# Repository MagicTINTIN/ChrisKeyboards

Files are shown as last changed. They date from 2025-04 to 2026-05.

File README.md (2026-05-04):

# ChrisKeyboards
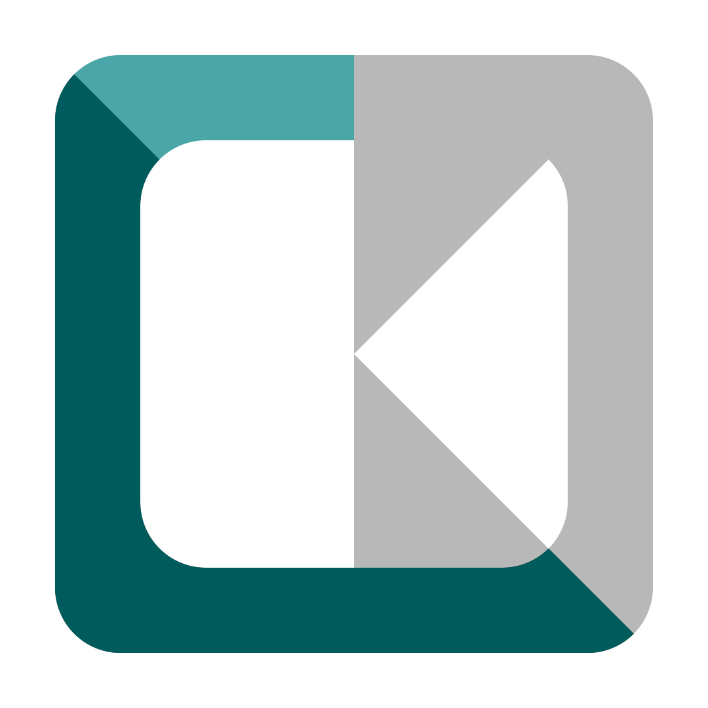
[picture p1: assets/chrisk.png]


> I couldn’t find the keyboard I wanted, so I built it.

---
Unable to find an USB chiclet keyboard as we have on laptop (and with a reasonable price), I decided to create mine.\
We can recover keyboard from an old laptop or buy a spare one (the one I chose is exactly the same that I have on my laptop, with backlight so it cost me 36 euros, but you can easily find cheaper ones).

## Components
- spare laptop keyboard (here with a 30 pins 0.8mm FPC ribbon)
- ESP32-S3 (we need about 30 IO pins...)
- 2 FPC connectors: 30 pins 0.8mm `for keys`, 6 pins (couldn't find 4 pins that meet requirements) 1mm `for backlight`
- Dupont cables while we don't have PCB
- (optional) speaker

## Road map
- [x] get components
- [x] assemble everything on a breadboard
- [x] program the esp32
- [x] testing the prototype in real conditions
- [x] implement missing features
- [ ] design PCB
- [ ] 3D model the case
- [ ] get last components
- [ ] print the case
- [ ] assemble the final keyboard

## Project pictures
ChrisT1_proto

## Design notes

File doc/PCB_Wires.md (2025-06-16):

I       30 ~        -
I7      29 ~        XX
I6      28 ~        XX
I4      27 ~        XX
I2      26 ~        XX
I5      25 ~        XX
I1      24 ~        XX
I3      23 ~        XX
IO      22 ~        XX
O5      21 ~        XX
O4      20 ~        XX
O7      19 ~        XX
O6      18 ~        XX
O8      17 ~        XX
O3      16 ~        XX
O1      15 ~        XX
O2      14 ~        XX
O0      13 ~        XX
O12     12 ~        XX
O16     11 ~        XX
O15     10 ~        XX
O13     09 ~        XX
O14     08 ~        XX
O9      07 ~        XX
O11     06 ~        XX
O10     05 ~        XX
CAP     04 ~   LED  XX (with R between them R1 = 220Ω)
o       03 ~        -
o       02 ~        -
o       01 ~   GND
Info    FPC-PIN     GPIO

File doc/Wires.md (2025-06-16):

S:  GPIO    I/PIN
-
I0: 40 ->  9|22
I1: 41 ->  7|24
I2: 42 ->  5|26
I3: 35 ->  8|23 //prev G43
I4: 36 ->  4|27 //prev G44
I5: 45 ->  6|25
I6: 47 ->  3|28
I7: 48 ->  2|29
O0: 4  -> 18|13
O1: 5  -> 16|15
O2: 6  -> 17|14
O3: 7  -> 15|16
O4: 8  -> 11|20
O5: 9  -> 10|21
O6: 10 -> 13|18
O7: 11 -> 12|19
O8: 12 -> 14|17
O9: 13 -> 24|7
O10:14 -> 26|5
O11:15 -> 25|6
O12:16 -> 19|12
O13:17 -> 22|9
O14:18 -> 23|8
O15:37 -> 21|10 //prev G19
O16:38 -> 20|11 //prev G20
LED:21 -> 27|4
-
-
GND

FPC-PIN     GPIO
02|29       48
03|28       47
04|27       44
05|26       42
06|25       45
07|24       41
08|23       43
09|22       40
10|21       9
11|20       8
12|19       11
13|18       10
14|17       12
15|16       7
16|15       5
17|14       6
18|13       4
19|12       16
20|11       20
21|10       19
22|9        17
23|8        18
24|7        13
25|6        15
26|5        14

FPC-PIN     GPIO
30 ~        -
29 ~        48
28 ~        47
27 ~        44
26 ~        42
25 ~        45
24 ~        41
23 ~        43
22 ~        40
21 ~        9
20 ~        8
19 ~        11
18 ~        10
17 ~        12
16 ~        7
15 ~        5
14 ~        6
13 ~        4
12 ~        16
11 ~        20
10 ~        19
09 ~        17
08 ~        18
07 ~        13
06 ~        15
05 ~        14
04 ~   LED  21 with R between them R1 = 220Ω
03 ~        -
02 ~        -
01 ~   GND

-
I0: -> 22
I1: -> 24
I2: -> 26
I3: -> 23
I4: -> 27
I5: -> 25
I6: -> 28
I7: -> 29
O0: -> 13
O1: -> 15
O2: -> 14
O3: -> 16
O4: -> 20
O5: -> 21
O6: -> 18
O7: -> 19
O8: -> 17
O9: -> 7
O10 -> 5
O11 -> 6
O12 -> 12
O13 -> 9
O14 -> 8
O15 -> 10
O16 -> 11
LED -> 4
-
-
GND

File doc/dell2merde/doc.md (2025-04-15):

Globalement y a pas grand chose à trouver sur internet.

Alors que : OMG
https://www.gadget-manual.com/dell/dell-laptop-schematics/

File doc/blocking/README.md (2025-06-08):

# Comment fonctionne l'algo de blocage pour empêcher les ghost keys
voici notre matrice de touches avec les colonnes 1 à 3 et nos lignes A à D permettant d'appuyer sur les touches 1 à C.
> [!NOTE]
> La matrice `mat` contient des booléens (réinitialisés à 0=false avant chaque frame)

> [!NOTE] Note n°2
> Ici la représentation suggère les colonnes envoient du courant séquentiellement. La représentation est plus compréhensible comme ça et cela fonctionne, mais ce n'est pas exactement ce qui est utilisé dans notre cas. Nous utilisons des colonnes en pull up qui passent en output open drain envoyant un 0 lorsqu'elles sont "actives" dans le scan, et repassent immédiatement après en input pull up.

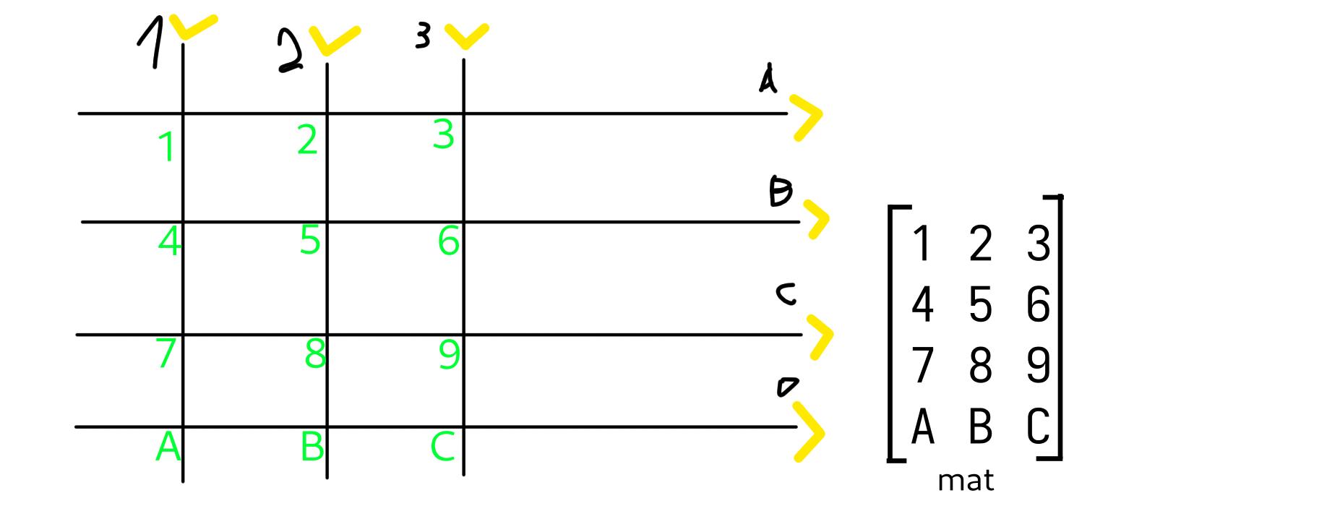
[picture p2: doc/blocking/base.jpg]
représentation de la matrice du clavier


## Scan sans problème
On décide d'appuyer sur 1 et C en premier
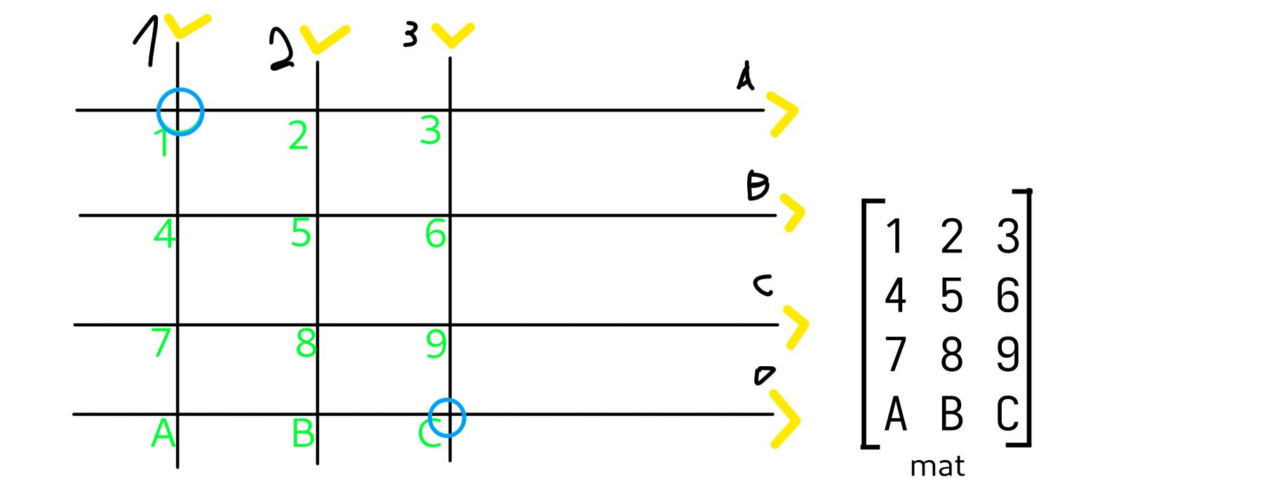
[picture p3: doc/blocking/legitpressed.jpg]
appui sur les touches 1 et C


Le scan passe et tout va bien
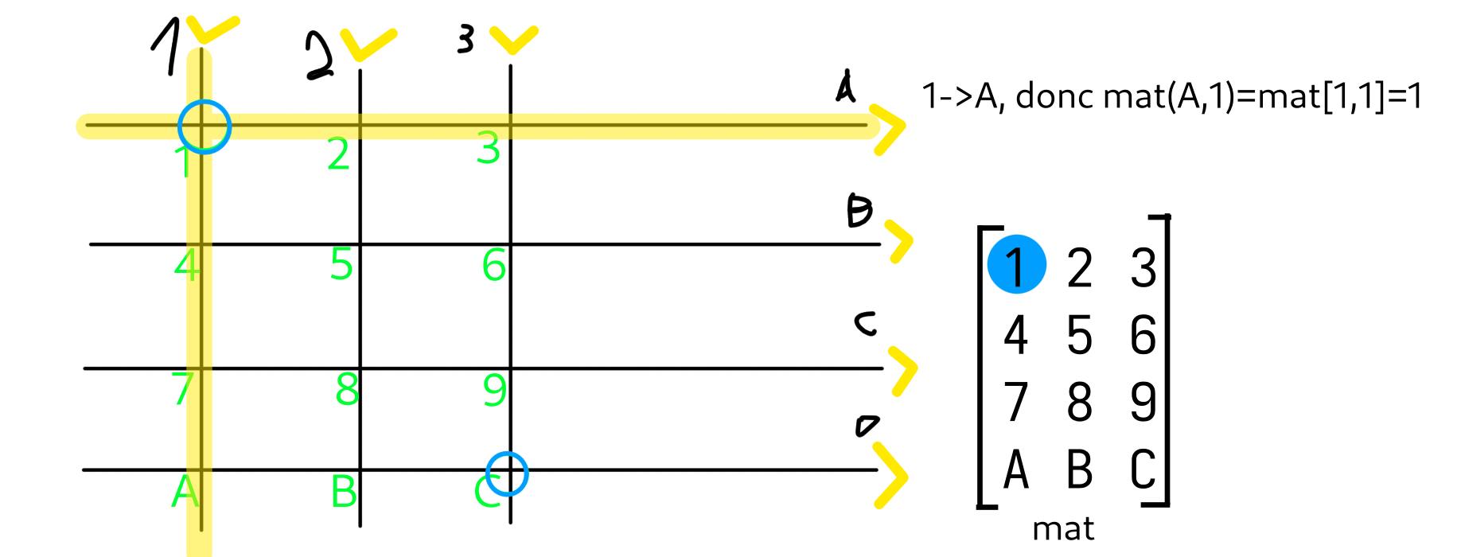
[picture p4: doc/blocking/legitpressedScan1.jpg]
Scan n°1 des touches 1 et C

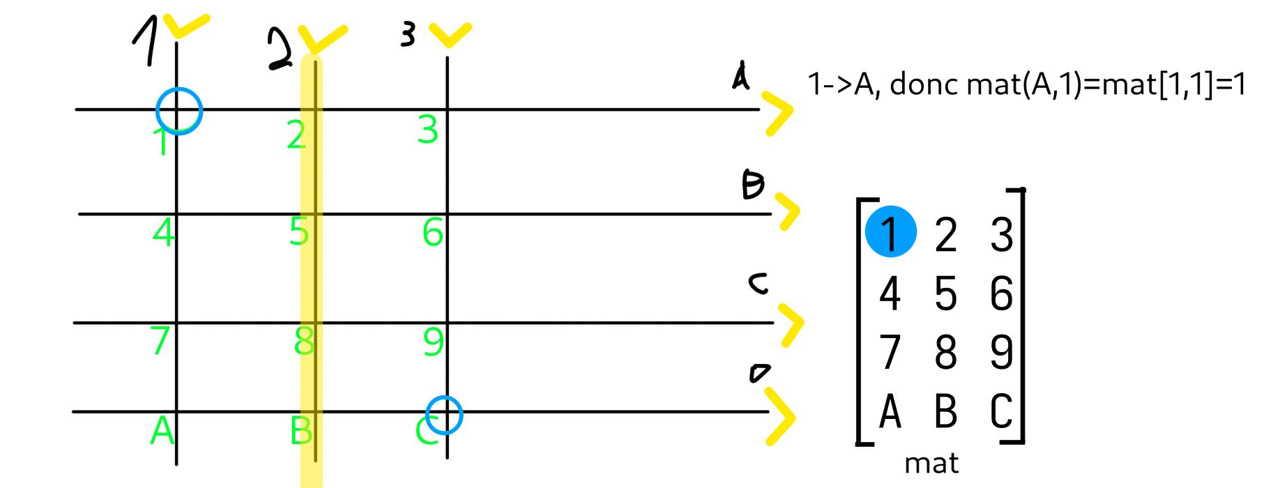
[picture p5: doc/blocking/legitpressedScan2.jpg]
Scan n°2 des touches 1 et C

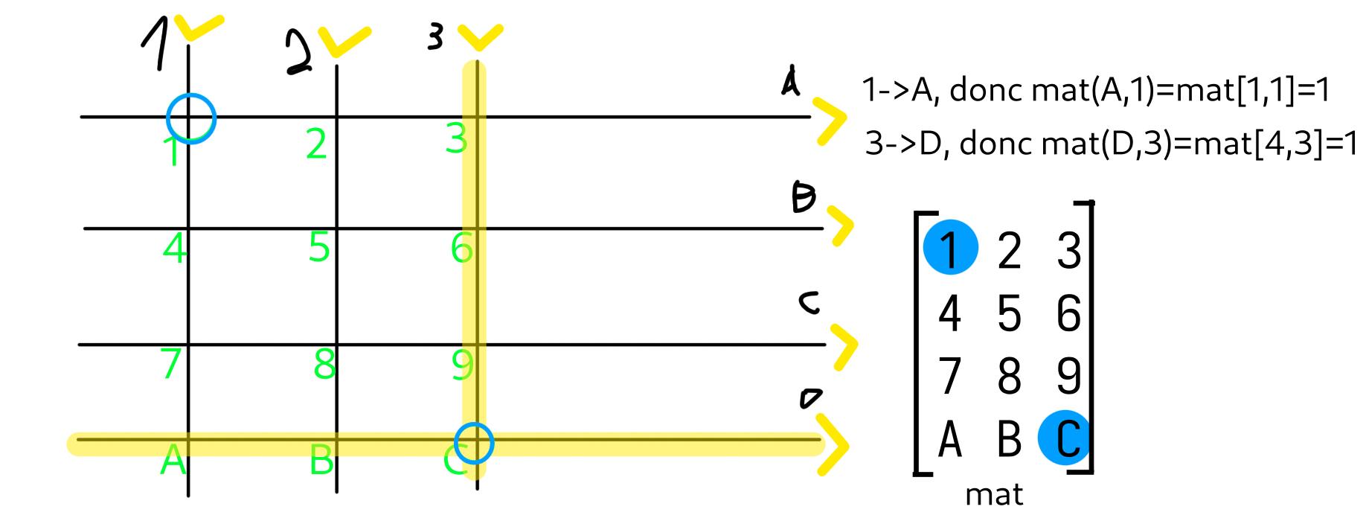
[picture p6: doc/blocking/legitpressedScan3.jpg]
Scan n°3 des touches 1 et C


Les touches détectées sont bonnes
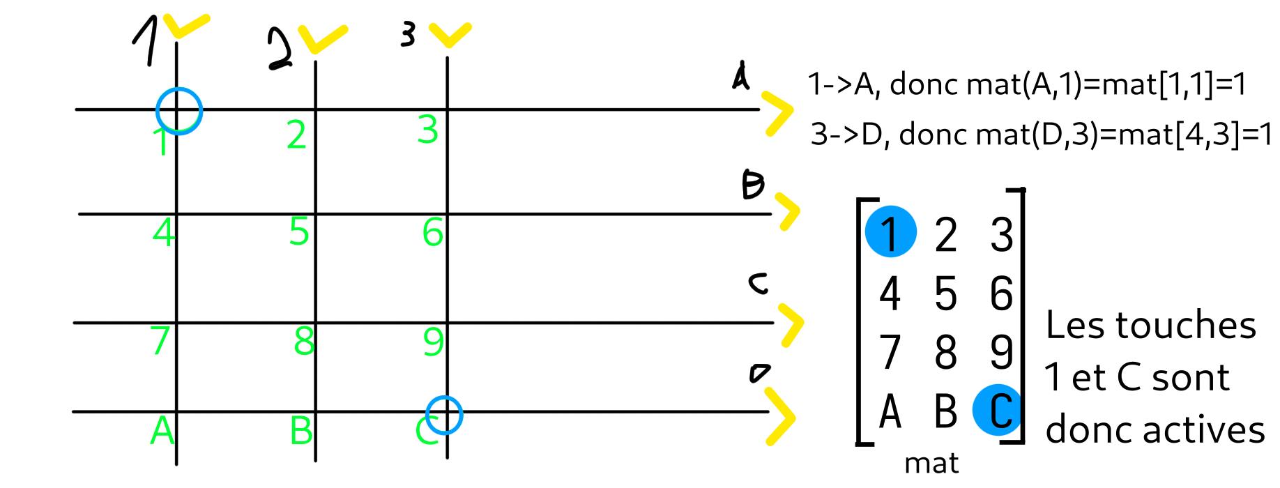
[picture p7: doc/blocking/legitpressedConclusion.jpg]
Conclusion du scanner sur 1 et C


## Le problème : apparition de ghost key

On décide maintenant d'ajouter A.
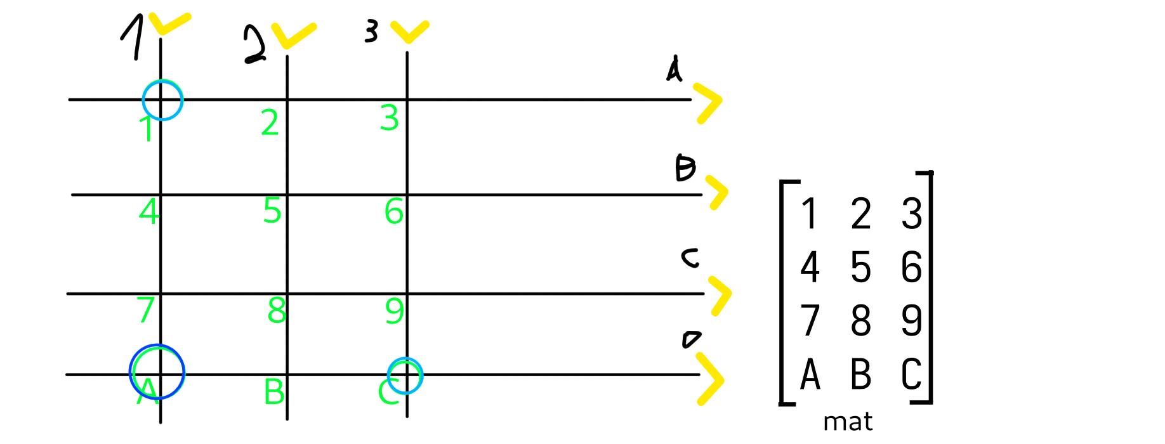
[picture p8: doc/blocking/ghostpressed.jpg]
appui sur les touches 1, A et C


Le scan passe et révèle 4 touches pressées
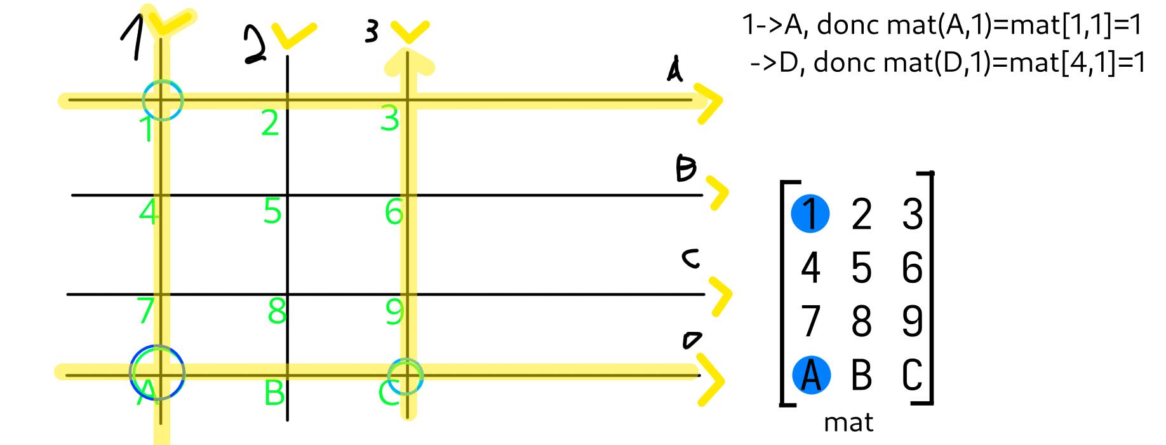
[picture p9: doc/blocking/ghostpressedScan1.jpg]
Scan n°1 des touches 1, A et C

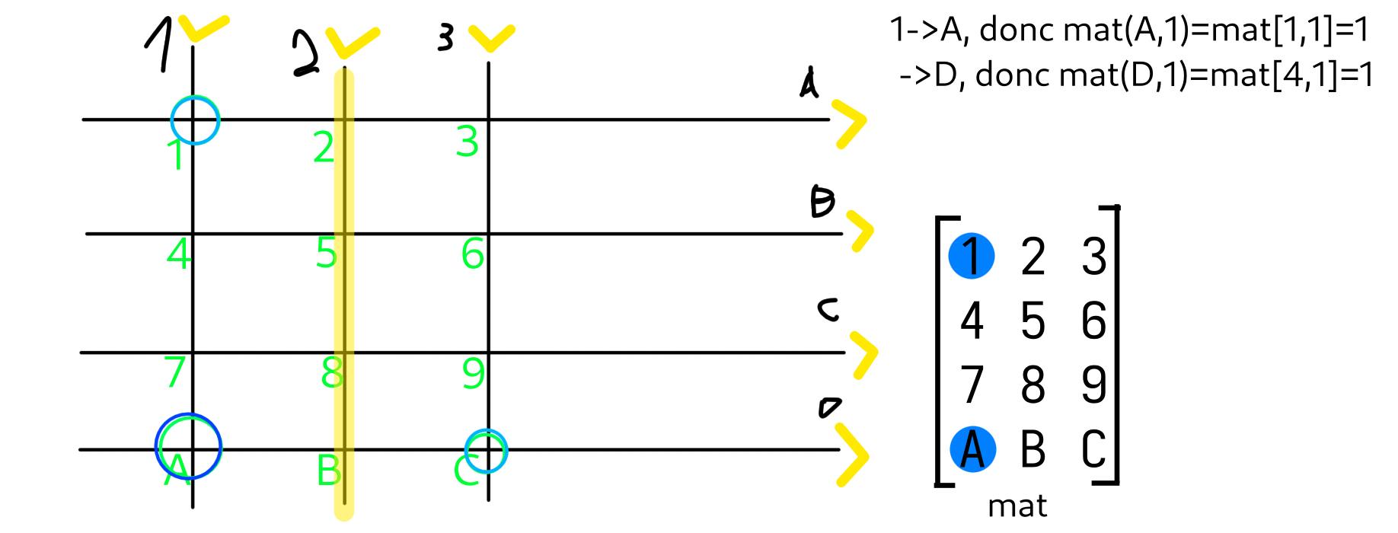
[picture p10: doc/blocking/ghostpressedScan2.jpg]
Scan n°2 des touches 1, A et C

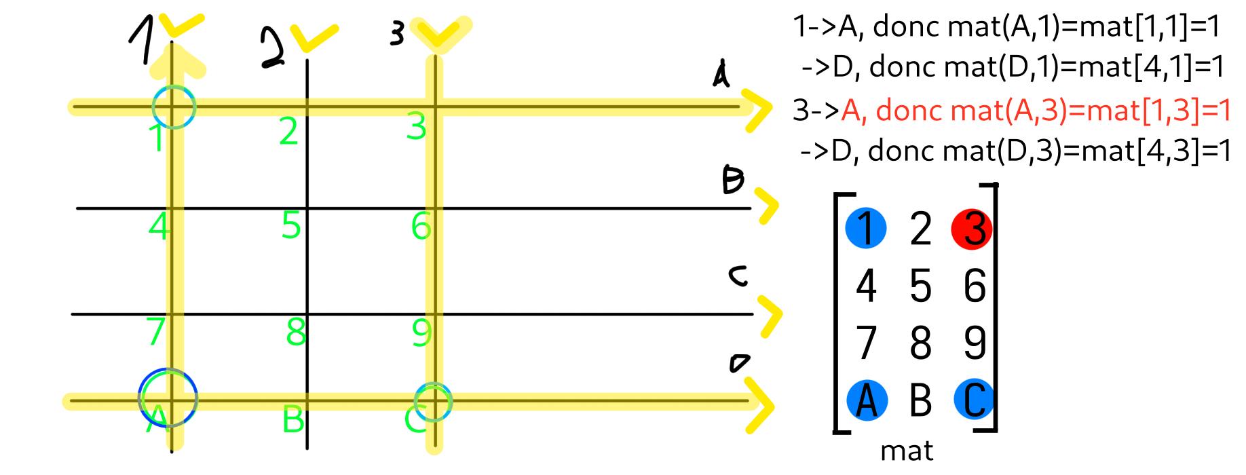
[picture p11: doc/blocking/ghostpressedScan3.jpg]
Scan n°3 des touches 1, A et C


La touche 3 est une ghost key
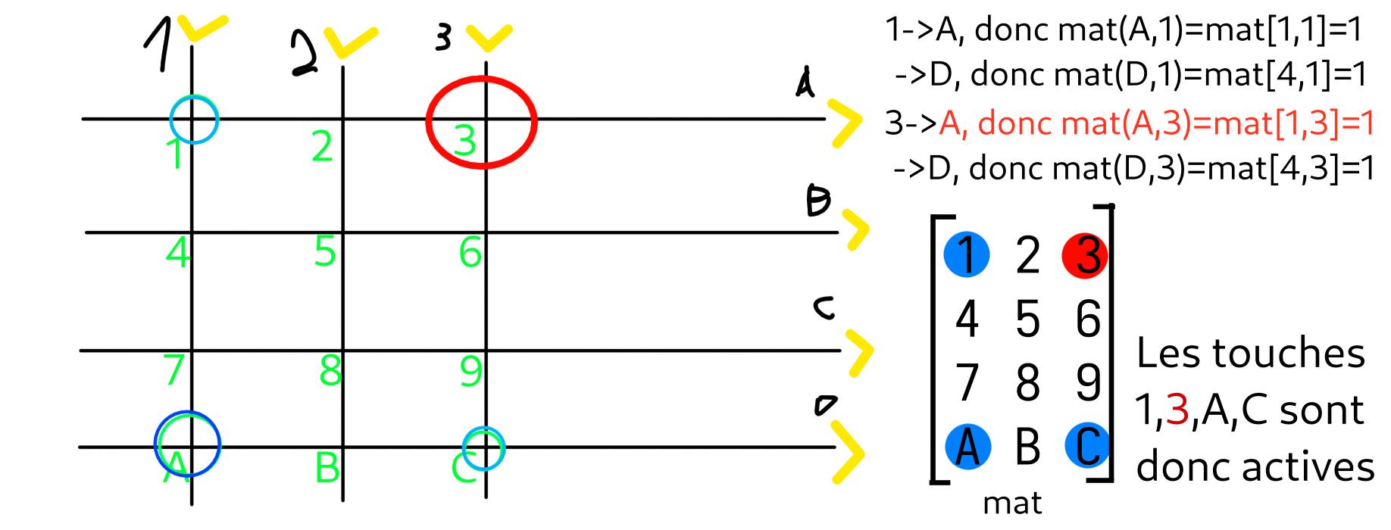
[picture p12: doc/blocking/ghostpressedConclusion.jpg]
Conclusion du scanner sur 1, A et C


## La solution
La solution pour les claviers diodeless est donc d'ajouter un algorithme de blocage. Celui-ci se trouve entre le scan et l'envoi des touches au système d'exploitation.
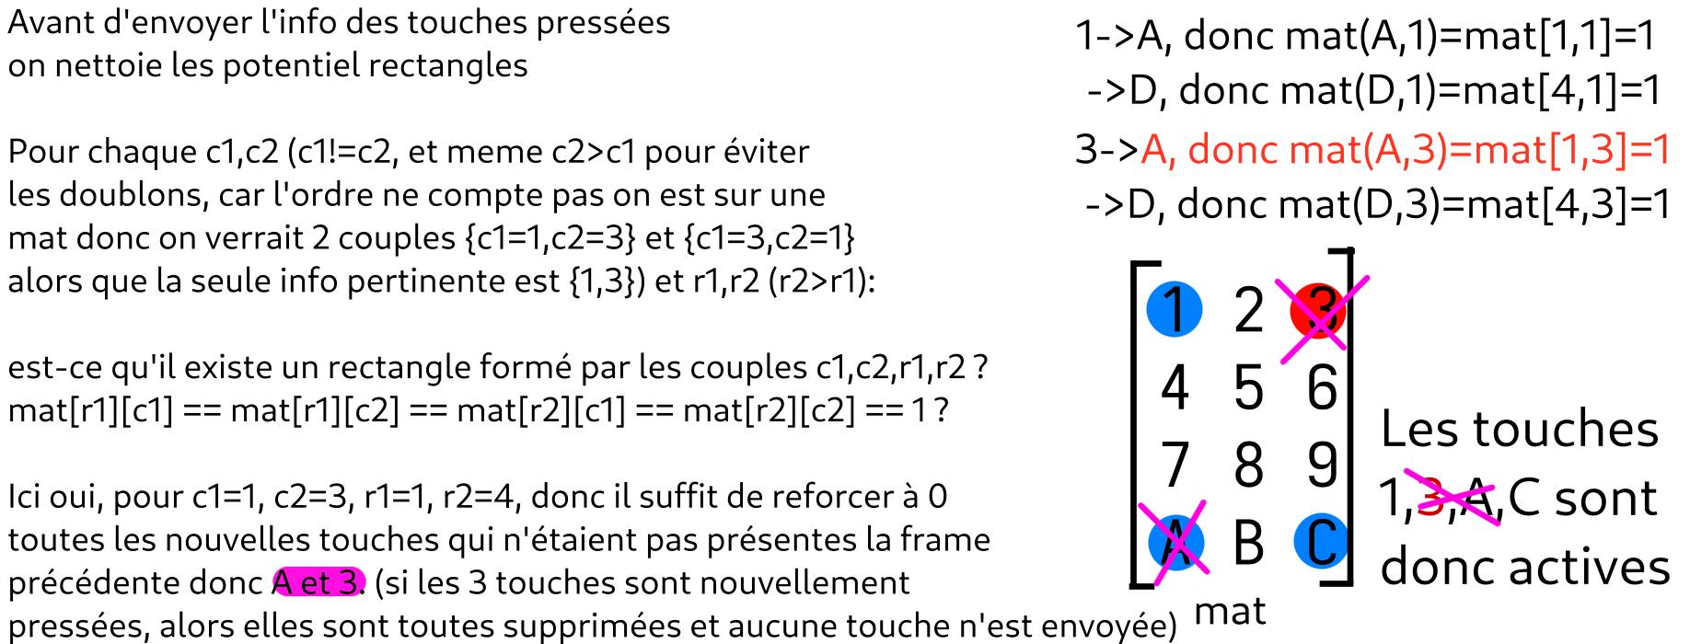
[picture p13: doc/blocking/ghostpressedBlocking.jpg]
Algoirthme solution


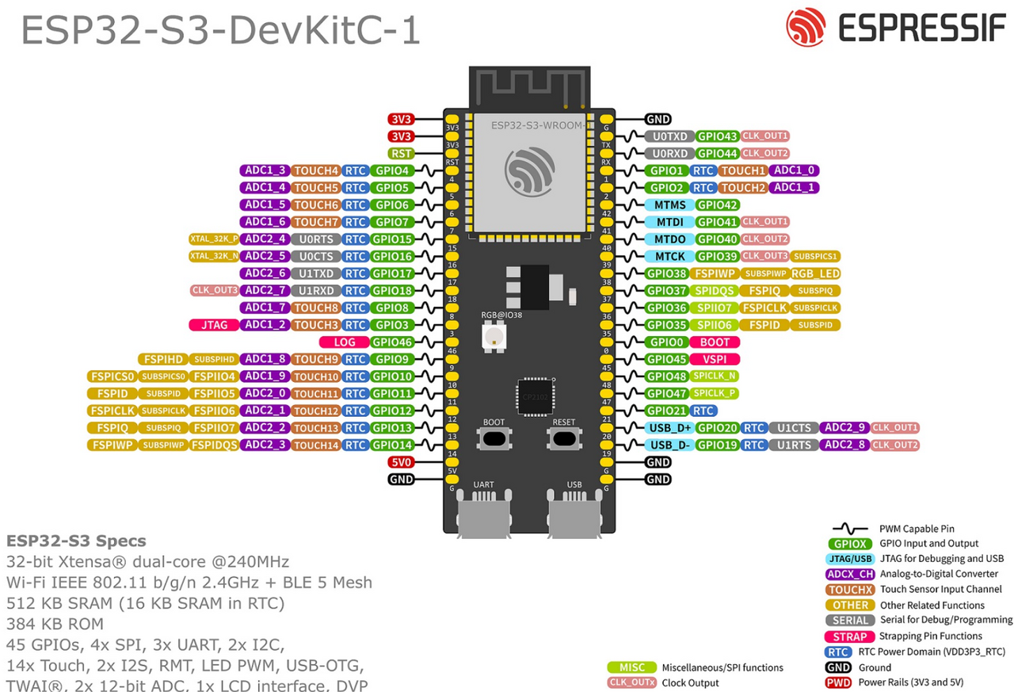
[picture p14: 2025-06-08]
doc/esp32/esp202b-3300364196.png

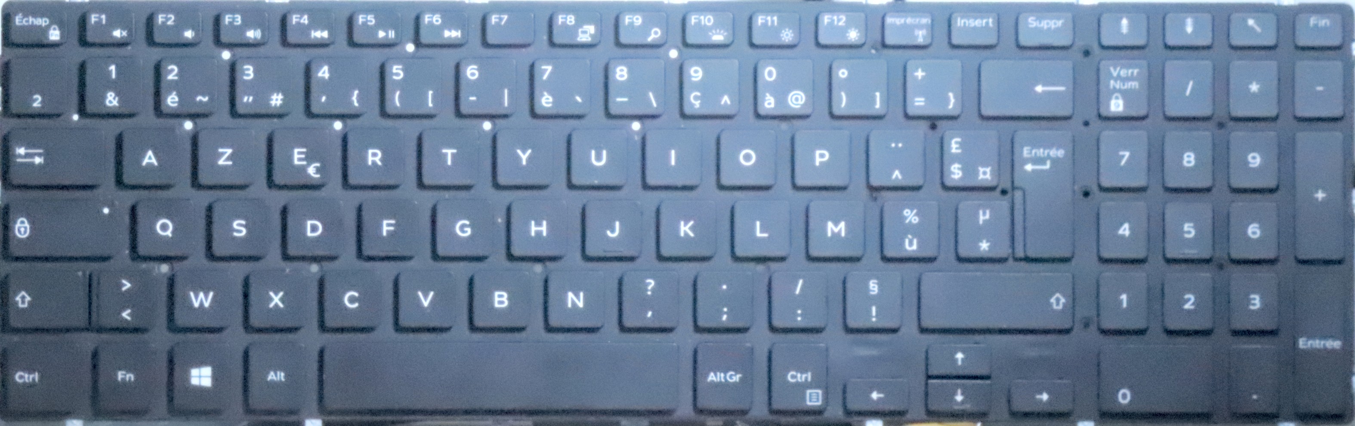
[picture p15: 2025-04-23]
doc/dell2merde/photo1280mm.jpg

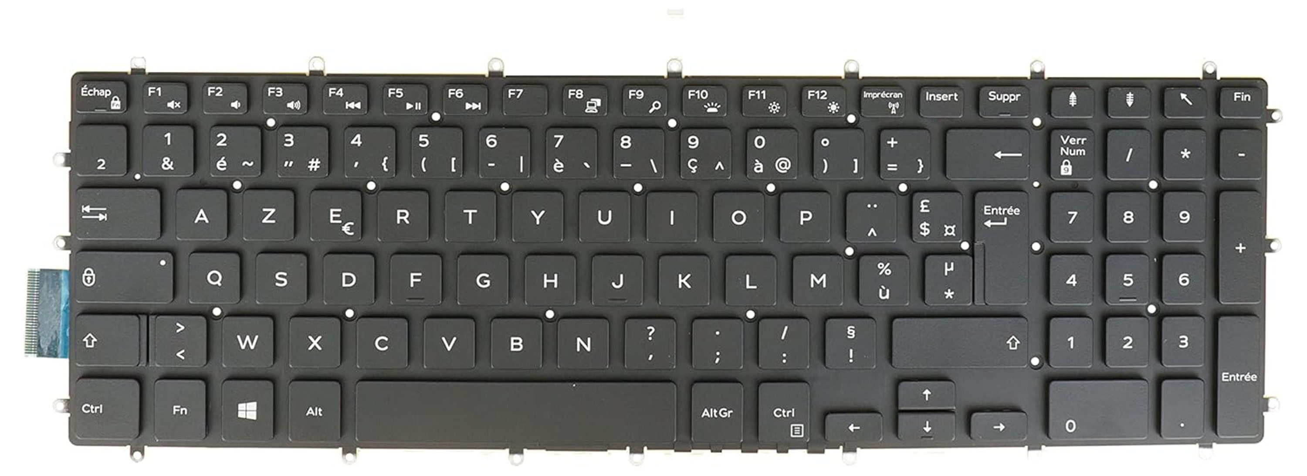
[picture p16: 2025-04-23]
doc/dell2merde/kbd.jpg

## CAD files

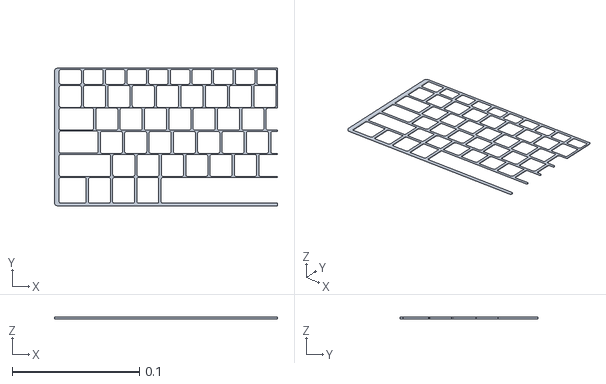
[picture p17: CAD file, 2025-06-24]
3DModel/split1m.stl
0.175 x 0.108 x 0.0012

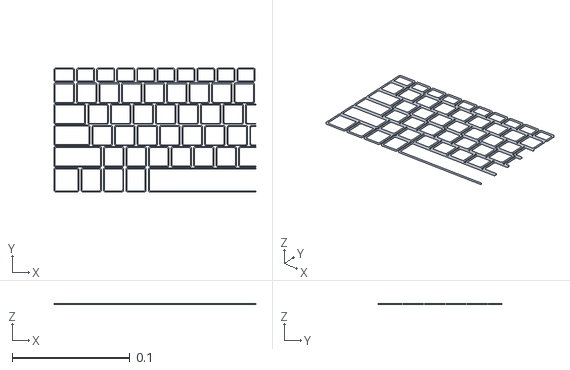
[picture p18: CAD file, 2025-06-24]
3DModel/split1c.stl
0.171 x 0.105 x 0.0012

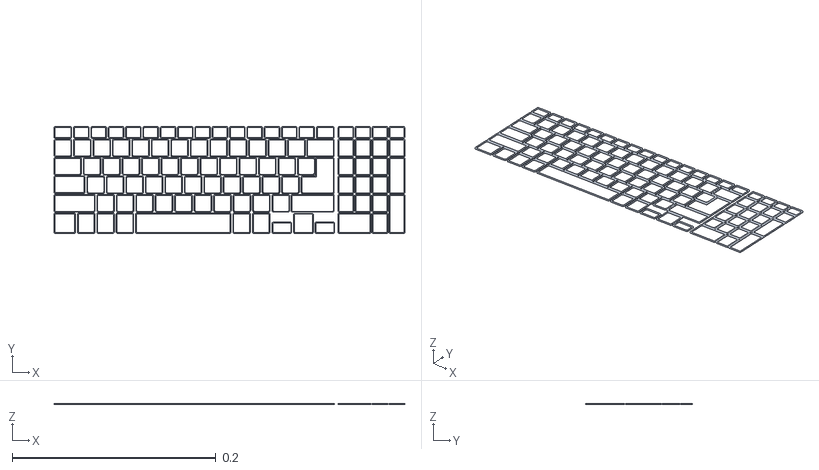
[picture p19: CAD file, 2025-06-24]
3DModel/v0.2c.stl
0.344 x 0.105 x 0.0012

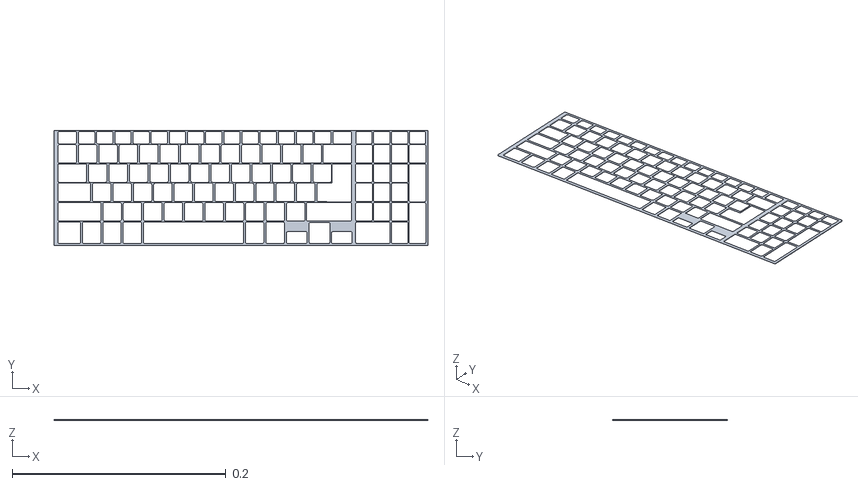
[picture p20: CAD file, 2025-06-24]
3DModel/v0.2m.stl
0.35 x 0.108 x 0.0012

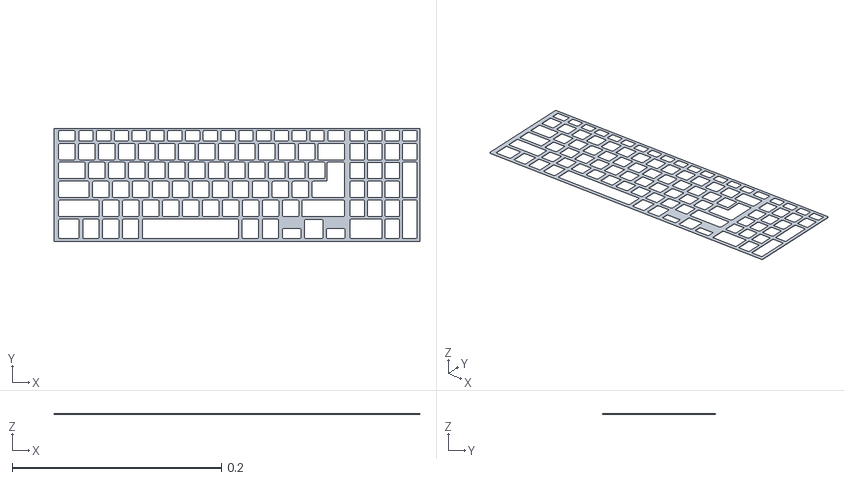
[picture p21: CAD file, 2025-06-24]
3DModel/v0.2.stl
0.35 x 0.108 x 0.0012

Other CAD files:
3DModel/v0.2.blend
3DModel/v0.blend

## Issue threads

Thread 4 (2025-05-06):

BUG: fnLock weird behaviour

MagicTINTIN, 2025-05-06:
Maybe no delay while switching from Locked or not ?

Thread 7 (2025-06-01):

feat: extension card

MagicTINTIN, 2025-06-01:
Check availability for extension.
1. in
2. out
3. clock
4. GND
5. 3.3V

Protocol to be defined between them.

Extension with a pico ? or nano.
- requirements for screen
- requirements for SD card R/W
- requirements for audio ? (jack)
- usb hub ?
- 5V ?

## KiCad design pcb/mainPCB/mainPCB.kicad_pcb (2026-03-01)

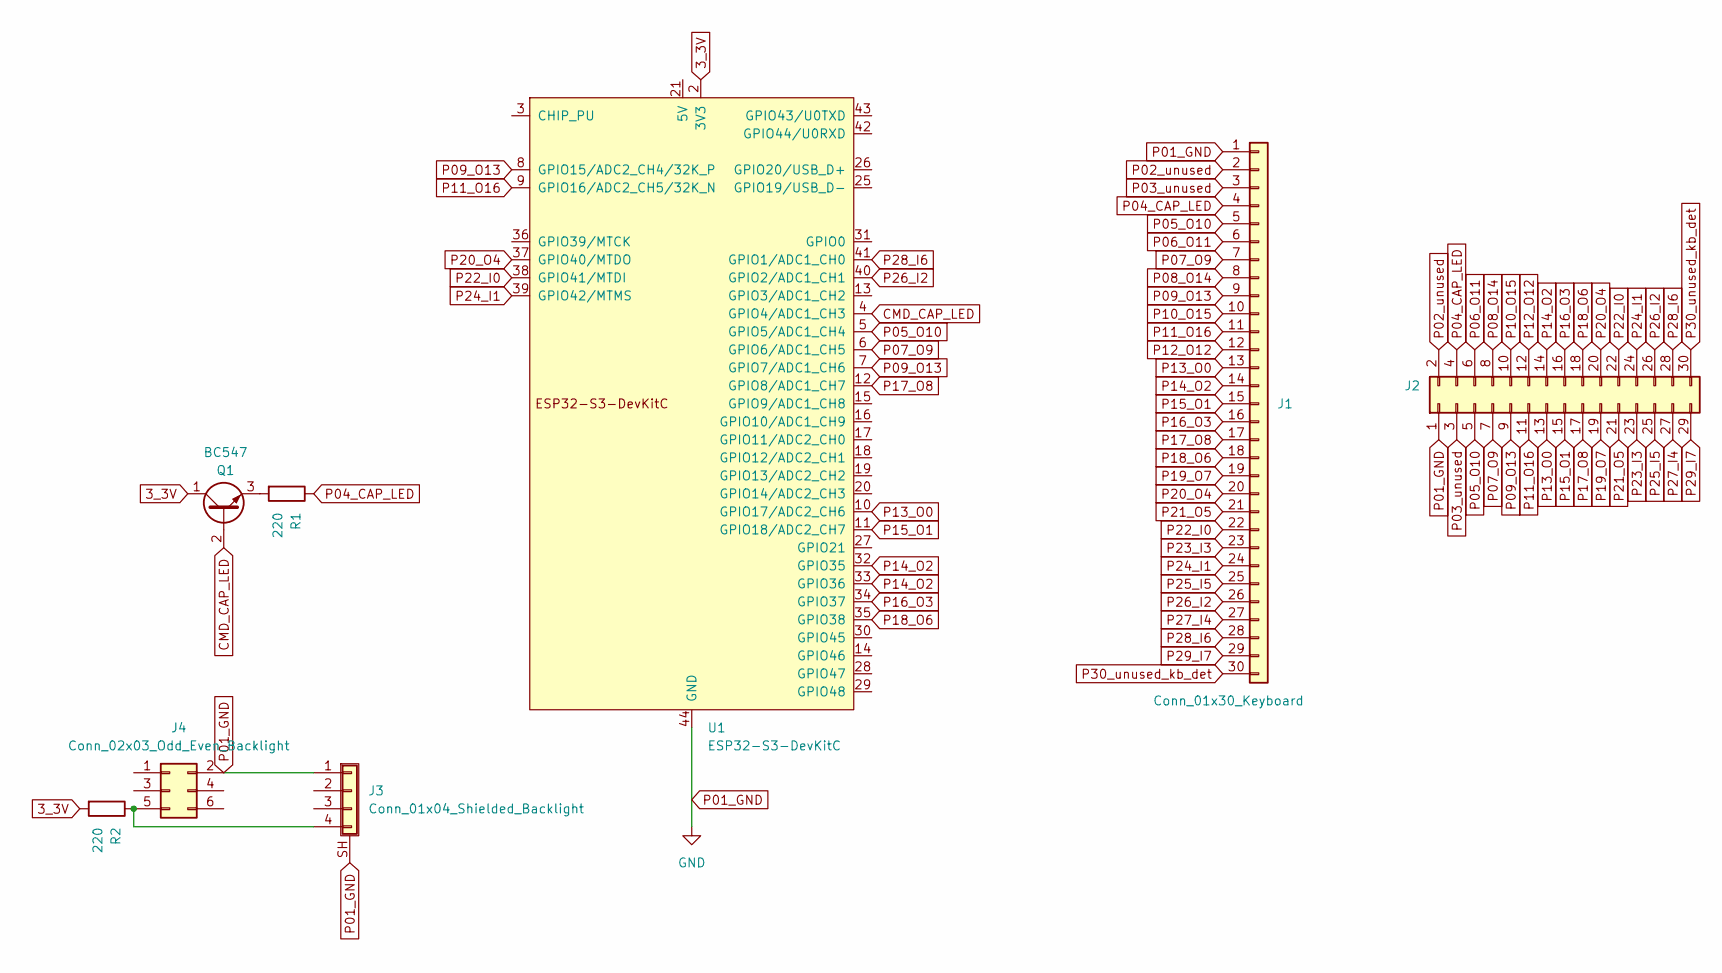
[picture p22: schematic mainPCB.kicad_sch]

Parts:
J1: Conn_01x30_Keyboard; FPC_30_Dell_0.8mm_no0
J2: Conn_02x15_Counter_Clockwise; PinHeader_2x15_P2.54mm_Vertical
J3: Conn_01x04_Shielded_Backlight; FPC_4_Dell_1mm_with0
J4: Conn_02x03_Odd_Even_Backlight; PinHeader_2x03_P2.00mm_Vertical
Q1: BC547; TO-92_Inline
R1, R2: 220; R_Axial_DIN0207_L6.3mm_D2.5mm_P10.16mm_Horizontal
U1: ESP32-S3-DevKitC

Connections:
3_3V: Q1.1 (C), R2.2, U1.1 (3V3), U1.2 (3V3)
CMD_CAP_LED: Q1.2 (B), U1.4 (GPIO4/ADC1_CH3)
unnamed: J3.4, J4.5, R2.1
unnamed: Q1.3 (E), R1.2
P01_GND: J1.1, J2.1, J3.1, J3.SH (Shield), J4.2, U1.22 (GND), U1.23 (GND), U1.24 (GND), U1.44 (GND)
P02_unused: J1.2, J2.2
P03_unused: J1.3, J2.3
P04_CAP_LED: J1.4, J2.4, R1.1
P05_O10: J1.5, J2.5, U1.5 (GPIO5/ADC1_CH4)
P06_O11: J1.6, J2.6
P07_O9: J1.7, J2.7, U1.6 (GPIO6/ADC1_CH5)
P08_O14: J1.8, J2.8
P09_O13: J1.9, J2.9, U1.7 (GPIO7/ADC1_CH6), U1.8 (GPIO15/ADC2_CH4/32K_P)
P10_O15: J1.10, J2.10
P11_O16: J1.11, J2.11, U1.9 (GPIO16/ADC2_CH5/32K_N)
P12_O12: J1.12, J2.12
P13_O0: J1.13, J2.13, U1.10 (GPIO17/ADC2_CH6)
P14_O2: J1.14, J2.14, U1.32 (GPIO35), U1.33 (GPIO36)
P15_O1: J1.15, J2.15, U1.11 (GPIO18/ADC2_CH7)
P16_O3: J1.16, J2.16, U1.34 (GPIO37)
P17_O8: J1.17, J2.17, U1.12 (GPIO8/ADC1_CH7)
P18_O6: J1.18, J2.18, U1.35 (GPIO38)
P19_O7: J1.19, J2.19
P20_O4: J1.20, J2.20, U1.37 (GPIO40/MTDO)
P21_O5: J1.21, J2.21
P22_I0: J1.22, J2.22, U1.38 (GPIO41/MTDI)
P23_I3: J1.23, J2.23
P24_I1: J1.24, J2.24, U1.39 (GPIO42/MTMS)
P25_I5: J1.25, J2.25
P26_I2: J1.26, J2.26, U1.40 (GPIO2/ADC1_CH1)
P27_I4: J1.27, J2.27
P28_I6: J1.28, J2.28, U1.41 (GPIO1/ADC1_CH0)
P29_I7: J1.29, J2.29
P30_unused_kb_det: J1.30, J2.30

Board: 2 copper layers, 8 parts (0 on the bottom side), 34 nets, no tracks yet.

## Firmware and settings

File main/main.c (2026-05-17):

// #define CFG_TUD_HID 2
#include "class/hid/hid.h"
#include "class/hid/hid_device.h"
#include "configuration.h"
#include "driver/gpio.h"
#include "driver/ledc.h"
#include "esp_log.h"
#include "freertos/FreeRTOS.h"
#include "freertos/semphr.h"
#include "freertos/task.h"
#include "nvs_flash.h"
#include "tinyusb.h"
#include <stdint.h>
#include <stdio.h>
#include <stdlib.h>
// #include "esp_task_wdt.h"
// #include <idf_additions.h>

#include "constants.h"
#include "esp_bt_defs.h"
#include "esp_gap_ble_api.h"
#include "esp_hidd_prf_api.h"
// #include "esp_bt_device.h"
// #include "esp_bt.h"
// #include "esp_bt_main.h"
// #include "esp_event.h"
// #include "esp_gatts_api.h"
// #include "esp_gatt_defs.h"
// #include "esp_system.h"
// #include "hid_dev.h"
// #include "nvs_flash.h"
#include "freertos/event_groups.h"
#include "stdio.h"
#include "string.h"

#define print_bits(x)                                                          \
  do {                                                                         \
    unsigned long long a__ = (x);                                              \
    size_t bits__ = sizeof(x) * 8;                                             \
    printf(#x ": ");                                                           \
    while (bits__--)                                                           \
      putchar(a__ & (1ULL << bits__) ? '1' : '0');                             \
    putchar('\n');                                                             \
  } while (0)

/************* TinyUSB descriptors ****************/

#define TUSB_DESC_TOTAL_LEN                                                    \
  (TUD_CONFIG_DESC_LEN + CFG_TUD_HID * TUD_HID_DESC_LEN)

// mouse and keyboard
static uint8_t const hid_mouse_keyboard_report_descriptor[] = {
    TUD_HID_REPORT_DESC_KEYBOARD(),
    // TUD_HID_REPORT_DESC_MOUSE(), // TODO:
};

// keyboard consumer (next/previous keys)
static uint8_t const hid_consumer_report_descriptor[] = {
    TUD_HID_REPORT_DESC_CONSUMER(HID_REPORT_ID(2))};

#define CONSUMER_REPORT_ID 2

// gamepad

/*
 * TUD_HID_REPORT_DESC_GAMEPAD
 * uint16_t buttons - 16 digital buttons (A/B/X/Y/LB/RB...)
 * int8_t   x, y    - left  stick  axis (-127 .. 127)
 * int8_t   z, rz   - right stick  axis (-127 .. 127)
 * int8_t   rx, ry  - analog triggers   (use  0  .. 127)
 * uint8_t  hat     - D-pad / hat switch (GAMEPAD_HAT_*)
 */
static uint8_t const hid_gamepad_report_descriptor[] = {
    TUD_HID_REPORT_DESC_GAMEPAD()};

// dummy
static const uint8_t hid_dummy1_descriptor[] = {
    HID_USAGE_PAGE_N(HID_USAGE_PAGE_VENDOR, 2),
    HID_USAGE(0x01),
    HID_COLLECTION(HID_COLLECTION_APPLICATION),
    HID_USAGE(0x01),
    HID_LOGICAL_MIN(0),
    HID_LOGICAL_MAX_N(255, 2),
    HID_REPORT_SIZE(8),
    HID_REPORT_COUNT(1),
    HID_INPUT(HID_DATA | HID_VARIABLE | HID_ABSOLUTE),
    HID_COLLECTION_END};

/**
 * @brief String descriptor
 */
const char *hid_string_descriptor[5] = {
    (char[]){4, TUSB_DESC_STRING, 0x0c, 0x04},
    "MagicTINTIN",     // 1: Manufacturer
    "ChrisT1 Clavier", // 2: Product
    "123456",          // 3: Serials, should use chip ID
    "CT1 Keyboard",    // 4: HID
};

/**
 * @brief Configuration descriptor
 *
 * This is a simple configuration descriptor that defines 1 configuration and 1
 * HID interface
 */
static const uint8_t hid_configuration_descriptor[] = {
    // Configuration number, interface count, string index, total length,
    // attribute, power in mA
    TUD_CONFIG_DESCRIPTOR(1, 5, 0, TUSB_DESC_TOTAL_LEN,
                          TUSB_DESC_CONFIG_ATT_REMOTE_WAKEUP, 100),

    // Interface number, string index, boot protocol, report descriptor len, EP
    // In address, size & polling interval
    // FIXME: booot protocol ?
    TUD_HID_DESCRIPTOR(HID_ITF_MOUSEKYB, 4, true,
                       sizeof(hid_mouse_keyboard_report_descriptor), 0x81, 16,
                       10),
    TUD_HID_DESCRIPTOR(HID_ITF_CONSUMER, 4, false,
                       sizeof(hid_consumer_report_descriptor), 0x82, 16, 10),
    TUD_HID_DESCRIPTOR(HID_ITF_GAMEPAD1, 4, false,
                       sizeof(hid_gamepad_report_descriptor), 0x83, 16, 10),
    TUD_HID_DESCRIPTOR(HID_ITF_GAMEPAD2, 4, false,
                       sizeof(hid_gamepad_report_descriptor), 0x84, 16, 10),
};

static volatile uint8_t g_enabled_gamepads_itfs = 0;
static volatile uint8_t g_enabled_gamepads_keys = 0;
static volatile uint8_t g_enabled_sounds_level = 1;

/********* TinyUSB HID callbacks ***************/

// Invoked when received GET HID REPORT DESCRIPTOR request
// Application return pointer to descriptor, whose contents must exist long
// enough for transfer to complete
uint8_t const *tud_hid_descriptor_report_cb(uint8_t instance) {
  switch (instance) {
  case HID_ITF_MOUSEKYB:
    return hid_mouse_keyboard_report_descriptor;
  case HID_ITF_CONSUMER:
    return hid_consumer_report_descriptor;
  case HID_ITF_GAMEPAD1:
    return g_enabled_gamepads_itfs > 0 ? hid_gamepad_report_descriptor
                                       : hid_dummy1_descriptor;
  case HID_ITF_GAMEPAD2:
    return g_enabled_gamepads_itfs > 1 ? hid_gamepad_report_descriptor
                                       : hid_dummy1_descriptor;
  default:
    return hid_mouse_keyboard_report_descriptor;
  }
}

// Invoked when received GET_REPORT control request
// Application must fill buffer report's content and return its length.
// Return zero will cause the stack to STALL request
uint16_t tud_hid_get_report_cb(uint8_t instance, uint8_t report_id,
                               hid_report_type_t report_type, uint8_t *buffer,
                               uint16_t reqlen) {
  (void)instance;
  (void)report_id;
  (void)report_type;
  (void)buffer;
  (void)reqlen;
  return 0;
}

static uint16_t hid_conn_id = 0;
static bool sec_conn = false;

static uint8_t hidd_service_uuid128[] = {
    /* LSB
       <-------------------------------------------------------------------------------->
       MSB */
    // first uuid, 16bit, [12],[13] is the value
    0xfb, 0x34, 0x9b, 0x5f, 0x80, 0x00, 0x00, 0x80,
    0x00, 0x10, 0x00, 0x00, 0x12, 0x18, 0x00, 0x00,
};

static esp_ble_adv_data_t hidd_adv_data = {
    .set_scan_rsp = false,
    .include_name = true,
    .include_txpower = true,
    .min_interval = 0x0006, // slave connection min interval, Time =
                            // min_interval * 1.25 msec
    .max_interval = 0x0010, // slave connection max interval, Time =
                            // max_interval * 1.25 msec
    .appearance = 0x03c0,   // HID Generic,
    .manufacturer_len = 0,
    .p_manufacturer_data = NULL,
    .service_data_len = 0,
    .p_service_data = NULL,
    .service_uuid_len = sizeof(hidd_service_uuid128),
    .p_service_uuid = hidd_service_uuid128,
    .flag = 0x6,
};

static esp_ble_adv_params_t hidd_adv_params = {
    .adv_int_min = 0x20,
    .adv_int_max = 0x30,
    .adv_type = ADV_TYPE_IND,
    .own_addr_type = BLE_ADDR_TYPE_PUBLIC,
    .channel_map = ADV_CHNL_ALL,
    .adv_filter_policy = ADV_FILTER_ALLOW_SCAN_ANY_CON_ANY,
};

static void hidd_event_callback(esp_hidd_cb_event_t event,
                                esp_hidd_cb_param_t *param) {
  switch (event) {
  case ESP_HIDD_EVENT_REG_FINISH:
    if (param->init_finish.state == ESP_HIDD_INIT_OK) {
      esp_ble_gap_set_device_name(HIDD_DEVICE_NAME);
      esp_ble_gap_config_adv_data(&hidd_adv_data);
    }
    break;
  case ESP_BAT_EVENT_REG:
    break;
  case ESP_HIDD_EVENT_DEINIT_FINISH:
    break;
  case ESP_HIDD_EVENT_BLE_CONNECT:
    ESP_LOGI(TAG, "ESP_HIDD_EVENT_BLE_CONNECT");
    hid_conn_id = param->connect.conn_id;
    break;
  case ESP_HIDD_EVENT_BLE_DISCONNECT:
    sec_conn = false;
    ESP_LOGI(TAG, "ESP_HIDD_EVENT_BLE_DISCONNECT");
    esp_ble_gap_start_advertising(&hidd_adv_params);
    break;
  case ESP_HIDD_EVENT_BLE_VENDOR_REPORT_WRITE_EVT:
    ESP_LOGI(TAG, "%s, ESP_HIDD_EVENT_BLE_VENDOR_REPORT_WRITE_EVT", __func__);
    ESP_LOG_BUFFER_HEX(TAG, param->vendor_write.data,
                       param->vendor_write.length);
    break;
  case ESP_HIDD_EVENT_BLE_LED_REPORT_WRITE_EVT:
    ESP_LOGI(TAG, "ESP_HIDD_EVENT_BLE_LED_REPORT_WRITE_EVT");
    ESP_LOG_BUFFER_HEX(TAG, param->led_write.data, param->led_write.length);
    if (param->led_write.length < 1)
      break;
    gpio_set_level(GPIO_CAPS_LED,
                   param->led_write.data[0] & KEYBOARD_LED_CAPSLOCK);
    break;
  default:
    break;
  }
}

static void gap_event_handler(esp_gap_ble_cb_event_t event,
                              esp_ble_gap_cb_param_t *param) {
  switch (event) {
  case ESP_GAP_BLE_ADV_DATA_SET_COMPLETE_EVT:
    esp_ble_gap_start_advertising(&hidd_adv_params);
    break;
  case ESP_GAP_BLE_SEC_REQ_EVT:
    for (int i = 0; i < ESP_BD_ADDR_LEN; i++)
      ESP_LOGD(TAG, "%x:", param->ble_security.ble_req.bd_addr[i]);
    esp_ble_gap_security_rsp(param->ble_security.ble_req.bd_addr, true);
    break;
  case ESP_GAP_BLE_AUTH_CMPL_EVT:
    sec_conn = true;
    esp_bd_addr_t bd_addr;
    memcpy(bd_addr, param->ble_security.auth_cmpl.bd_addr,
           sizeof(esp_bd_addr_t));
    ESP_LOGI(TAG, "remote BD_ADDR: %08x%04x",
             (bd_addr[0] << 24) + (bd_addr[1] << 16) + (bd_addr[2] << 8) +
                 bd_addr[3],
             (bd_addr[4] << 8) + bd_addr[5]);
    ESP_LOGI(TAG, "address type = %d", param->ble_security.auth_cmpl.addr_type);
    ESP_LOGI(TAG, "pair status = %s",
             param->ble_security.auth_cmpl.success ? "success" : "fail");
    if (!param->ble_security.auth_cmpl.success)
      ESP_LOGE(TAG, "fail reason = 0x%x",
               param->ble_security.auth_cmpl.fail_reason);
    break;
  default:
    break;
  }
}

bool caps_on = false;

void tud_hid_set_report_cb(uint8_t instance, uint8_t report_id,
                           hid_report_type_t report_type, const uint8_t *buffer,
                           uint16_t bufsize) {
  if (instance != 0)
    return; // keyboard is interface 0
  if (report_type != HID_REPORT_TYPE_OUTPUT)
    return;
  if (bufsize < 1)
    return;

  uint8_t leds = buffer[0];

  caps_on = leds & KEYBOARD_LED_CAPSLOCK; // from hid.h bitmask
  // printf("Caps LED %s\n", caps_on ? "ON" : "OFF");

  gpio_set_level(GPIO_CAPS_LED, caps_on);
}

void buzzer_init(void) {
  // NOTE: buzzer_init() is currently unused -> start_buzzer_task() is called
  // instead.
  // TODO: remove ?
  ledc_timer_config_t ledc_timer = {
      .speed_mode = LEDC_LOW_SPEED_MODE,
      .duty_resolution = LEDC_TIMER_10_BIT,
      .timer_num = BUZZER_TIMER,
      .freq_hz = 5000,
      .clk_cfg = LEDC_AUTO_CLK,
      .deconfigure = false,
  };
  ledc_timer_config(&ledc_timer);

  ledc_channel_config_t ledc_channel = {
      .gpio_num = BUZZER_GPIO,
      .speed_mode = LEDC_LOW_SPEED_MODE,
      .channel = BUZZER_CHANNEL,
      .timer_sel = BUZZER_TIMER,
      .duty = 0,
      .hpoint = 0,
      // intr_type removed in IDF 6.0 (field deprecated and dropped)
  };
  ledc_channel_config(&ledc_channel);
}

void buzzer_quack(void) {
  int freq = 880; // A5 note
  int duty = 512; // 50% of 10-bit resolution (0–1023)

  ledc_set_freq(LEDC_LOW_SPEED_MODE, BUZZER_TIMER, freq);
  ledc_set_duty(LEDC_LOW_SPEED_MODE, BUZZER_CHANNEL, duty);
  ledc_update_duty(LEDC_LOW_SPEED_MODE, BUZZER_CHANNEL);

  vTaskDelay(pdMS_TO_TICKS(150)); // play for 150 ms

  // stop the sound
  ledc_set_duty(LEDC_LOW_SPEED_MODE, BUZZER_CHANNEL, 0);
  ledc_update_duty(LEDC_LOW_SPEED_MODE, BUZZER_CHANNEL);
}

#define STACK_SIZE 2048

// Static memory for the task
StaticTask_t buzzerTaskTCB;
StackType_t buzzerTaskStack[STACK_SIZE];

static TaskHandle_t buzzer_task_handle = NULL;
static volatile bool buzzer_running = false;

void buzzer_task(void *param) {
  ledc_timer_config_t ledc_timer = {
      .speed_mode = LEDC_LOW_SPEED_MODE,    // speed_mode
      .duty_resolution = LEDC_TIMER_10_BIT, // timer_num
      .timer_num = BUZZER_TIMER,            // duty_resolution
      .freq_hz = 200,                       // freq_hz
      .clk_cfg = LEDC_AUTO_CLK,             // clk_cfg
      .deconfigure = false,                 // deconfigure (ajout si nécessaire)
  };
  ledc_timer_config(&ledc_timer);

  ledc_channel_config_t ledc_channel = {.gpio_num = BUZZER_GPIO,
                                        .speed_mode = LEDC_LOW_SPEED_MODE,
                                        .channel = LEDC_CHANNEL_0,
                                        // .intr_type = LEDC_INTR_DISABLE,
                                        .timer_sel = LEDC_TIMER_0,
                                        .duty = 0, // 50%
                                        .hpoint = 0};
  ledc_channel_config(&ledc_channel);

  while (1) {
    uint32_t duty = buzzer_running && g_enabled_sounds_level > 0 ? 512 : 0;
    ledc_set_duty(ledc_channel.speed_mode, ledc_channel.channel, duty);
    ledc_update_duty(ledc_channel.speed_mode, ledc_channel.channel);
    vTaskDelay(pdMS_TO_TICKS(10)); // avoid busy wait
  }
}

void start_buzzer_task(void) {
  buzzer_task_handle =
      xTaskCreateStatic(buzzer_task,     // Task function
                        "BuzzerTask",    // Name
                        STACK_SIZE,      // Stack size in words, not bytes
                        NULL,            // Parameter
                        5,               // Priority
                        buzzerTaskStack, // Stack array
                        &buzzerTaskTCB   // Task control block
      );
}

void buzzer_on(void) { buzzer_running = true; }
void buzzer_off(void) { buzzer_running = false; }

// Static memory for the startup task
StaticTask_t startupTaskTCB;
StackType_t startupTaskStack[STACK_SIZE];
static TaskHandle_t startup_task_handle = NULL;
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
void app_main(void) {
  // get current configuration
  esp_err_t ret = nvs_flash_init();
  if (ret == ESP_ERR_NVS_NO_FREE_PAGES ||
      ret == ESP_ERR_NVS_NEW_VERSION_FOUND) {
    ESP_LOGW(TAG, "NVS partition needs erase, reformatting…");
    ESP_ERROR_CHECK(nvs_flash_erase());
    ret = nvs_flash_init();
  }
  ESP_ERROR_CHECK(ret);

  g_enabled_gamepads_itfs = cfg_read_enabled_gamepads();
  g_enabled_gamepads_keys = cfg_read_enabled_gamepads_keys();
  g_enabled_sounds_level = cfg_get_sounds_level();
  ESP_LOGI(TAG, "Config: enabled_gamepads_interfaces=%d (active: %d)",
           g_enabled_gamepads_itfs, g_enabled_gamepads_keys);

  // GPIOs for columns (KSIs, ESP outputs)
  const gpio_num_t cols[] = {
      GPIO_NUM_40, GPIO_NUM_41, GPIO_NUM_42, GPIO_NUM_35,
      GPIO_NUM_36, GPIO_NUM_45, GPIO_NUM_47, GPIO_NUM_48,
  };
  const int num_cols = sizeof(cols) / sizeof(cols[0]);

  // GPIOs for rows (KSOs, ESP inputs)
  const gpio_num_t rows[] = {
      GPIO_NUM_4,  GPIO_NUM_5,  GPIO_NUM_6,  GPIO_NUM_7,  GPIO_NUM_8,
      GPIO_NUM_9,  GPIO_NUM_10, GPIO_NUM_11, GPIO_NUM_12, GPIO_NUM_13,
      GPIO_NUM_14, GPIO_NUM_15, GPIO_NUM_16, GPIO_NUM_17, GPIO_NUM_18,
      GPIO_NUM_37, GPIO_NUM_38,
  };
  const int num_rows = sizeof(rows) / sizeof(rows[0]);

  // --- Configure rows (inputs with pull-up) ---
  for (int i = 0; i < num_rows; ++i) {
    gpio_config_t row_conf = {
        .pin_bit_mask = 1ULL << rows[i],
        .mode = GPIO_MODE_INPUT,
        .pull_up_en = GPIO_PULLUP_ENABLE,
        .pull_down_en = GPIO_PULLDOWN_DISABLE,
        .intr_type = GPIO_INTR_DISABLE,
    };
    gpio_config(&row_conf);
  }

  // --- Configure columns (initially inputs with pull-up; driven LOW one at a
  // time during scan) ---
  for (int i = 0; i < num_cols; ++i) {
    vTaskDelay(pdMS_TO_TICKS(20));
    gpio_config_t col_conf = {
        .pin_bit_mask = 1ULL << cols[i],
        .mode = GPIO_MODE_INPUT,
        .pull_up_en = GPIO_PULLUP_ENABLE,
        .pull_down_en = GPIO_PULLDOWN_DISABLE,
        .intr_type = GPIO_INTR_DISABLE,
    };
    gpio_config(&col_conf);

    // all columns are HIGH initially
    // gpio_set_level(cols[i], 1);
    vTaskDelay(pdMS_TO_TICKS(20));
  }

  vTaskDelay(pdMS_TO_TICKS(20));

  gpio_config_t back_conf = {
      .pin_bit_mask = 1ULL << GPIO_NUM_3,
      .mode = GPIO_MODE_INPUT,
      .pull_up_en = GPIO_PULLUP_ENABLE,
      .pull_down_en = GPIO_PULLDOWN_DISABLE,
      .intr_type = GPIO_INTR_DISABLE,
  };
  gpio_config(&back_conf);

  gpio_config_t caps_led_conf = {
      .pin_bit_mask = 1ULL << GPIO_CAPS_LED,
      .mode = GPIO_MODE_OUTPUT,
      .pull_up_en = GPIO_PULLUP_DISABLE,
      .pull_down_en = GPIO_PULLDOWN_DISABLE,
      .intr_type = GPIO_INTR_DISABLE,
  };
  gpio_config(&caps_led_conf);

  start_buzzer_task();
  start_startup_info_task();

  const tinyusb_config_t tusb_cfg = {
      .device_descriptor = NULL,
      .string_descriptor = hid_string_descriptor,
      .string_descriptor_count =
          sizeof(hid_string_descriptor) / sizeof(hid_string_descriptor[0]),
      .external_phy = false,
#if (TUD_OPT_HIGH_SPEED)
      .fs_configuration_descriptor =
          hid_configuration_descriptor, // HID configuration descriptor for
                                        // full-speed and high-speed are the
                                        // same
      .hs_configuration_descriptor = hid_configuration_descriptor,
      .qualifier_descriptor = NULL,
#else
      .configuration_descriptor = hid_configuration_descriptor,
#endif // TUD_OPT_HIGH_SPEED
  };

  ESP_ERROR_CHECK(tinyusb_driver_install(&tusb_cfg));

  // BLUETOOTH

  // if re-enabling BLE in IDF 6.0, NOTE:
  //   esp_bt_dev_set_device_name() → esp_bt_gap_set_device_name()  (Classic BT)
  //   esp_bt_dev_get_device_name() → esp_bt_gap_get_device_name()  (Classic BT)
  //   BLE GAP: esp_ble_gap_set_device_name() unchanged.

  // esp_err_t ret;

  // Initialize NVS.
  // ret = nvs_flash_init();
  // if (ret == ESP_ERR_NVS_NO_FREE_PAGES || ret ==
  // ESP_ERR_NVS_NEW_VERSION_FOUND)
  // {
  //     ESP_ERROR_CHECK(nvs_flash_erase());
  //     ret = nvs_flash_init();
  // }
  // ESP_ERROR_CHECK(ret);

  // ESP_ERROR_CHECK(esp_bt_controller_mem_release(ESP_BT_MODE_CLASSIC_BT));

  // esp_bt_controller_config_t bt_cfg = BT_CONTROLLER_INIT_CONFIG_DEFAULT();
  // ret = esp_bt_controller_init(&bt_cfg);
  // if (ret)
  // {
  //     ESP_LOGE(TAG, "%s initialize controller failed", __func__);
  //     return;
  // }

  // ret = esp_bt_controller_enable(ESP_BT_MODE_BLE);
  // if (ret)
  // {
  //     ESP_LOGE(TAG, "%s enable controller failed", __func__);
  //     return;
  // }

  // ret = esp_bluedroid_init();
  // if (ret)
  // {
  //     ESP_LOGE(TAG, "%s init bluedroid failed", __func__);
  //     return;
  // }

  // ret = esp_bluedroid_enable();
  // if (ret)
  // {
  //     ESP_LOGE(TAG, "%s init bluedroid failed", __func__);
  //     return;
  // }

  // if ((ret = esp_hidd_profile_init()) != ESP_OK)
  // {
  //     ESP_LOGE(TAG, "%s init bluedroid failed", __func__);
  // }

  // /// register the callback function to the gap module
  // esp_ble_gap_register_callback(gap_event_handler);
  // esp_hidd_register_callbacks(hidd_event_callback);

  // /* set the security iocap & auth_req & key size & init key response key
  // parameters to the stack*/ esp_ble_auth_req_t auth_req = ESP_LE_AUTH_BOND;
  // // bonding with peer device after authentication esp_ble_io_cap_t iocap =
  // ESP_IO_CAP_NONE;       // set the IO capability to No output No input
  // uint8_t key_size = 16;                          // the key size should be
  // 7~16 bytes uint8_t init_key = ESP_BLE_ENC_KEY_MASK | ESP_BLE_ID_KEY_MASK;
  // uint8_t rsp_key = ESP_BLE_ENC_KEY_MASK | ESP_BLE_ID_KEY_MASK;
  // esp_ble_gap_set_security_param(ESP_BLE_SM_AUTHEN_REQ_MODE, &auth_req,
  // sizeof(uint8_t)); esp_ble_gap_set_security_param(ESP_BLE_SM_IOCAP_MODE,
  // &iocap, sizeof(uint8_t));
  // esp_ble_gap_set_security_param(ESP_BLE_SM_MAX_KEY_SIZE, &key_size,
  // sizeof(uint8_t));
  // /* If your BLE device act as a Slave, the init_key means you hope which
  // types of key of the master should distribute to you, and the response key
  // means which key you can distribute to the Master; If your BLE device act as
  // a master, the response key means you hope which types of key of the slave
  // should distribute to you, and the init key means which key you can
  // distribute to the slave. */
  // esp_ble_gap_set_security_param(ESP_BLE_SM_SET_INIT_KEY, &init_key,
  // sizeof(uint8_t)); esp_ble_gap_set_security_param(ESP_BLE_SM_SET_RSP_KEY,
  // &rsp_key, sizeof(uint8_t));

  // MAIN LOOP

  while (true) {
    if (tud_mounted()) {
      for (int col = 0; col < num_cols; ++col) {
        // current to column LOW, rest HIGH
        for (int i = 0; i < num_cols; ++i) {
          if (i == col) {
            gpio_set_direction(cols[i], GPIO_MODE_OUTPUT_OD);
            gpio_set_level(cols[i], 0);
          } else {
            gpio_config_t col_conf = {
                .pin_bit_mask = 1ULL << cols[i],
                .mode = GPIO_MODE_INPUT,
                .pull_up_en = GPIO_PULLUP_ENABLE,
                .pull_down_en = GPIO_PULLDOWN_DISABLE,
                .intr_type = GPIO_INTR_DISABLE,
            };
            gpio_config(&col_conf);
          }
          // gpio_set_level(cols[i], i == col ? 0 : 1);
        }

        // small delay for signal to settle
        esp_rom_delay_us(10); // seems sufficient ? check without debug prints

        // read all rows
        for (int row = 0; row < num_rows; ++row) {
          if (gpio_get_level(rows[row]) == 0)
            raw[col][row] = 1;
          // keyPressRegistration(col, row);
        }
      }
      deghostBlockingAndRegister();
      keyUpdateRegistration();
    }

    // delay before next scan
    vTaskDelay(pdMS_TO_TICKS(10));
    buzzer_off();
  }
}

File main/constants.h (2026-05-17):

#pragma once

#ifndef CONSTANTS_H
#define CONSTANTS_H
#include "class/hid/hid.h"
#include <stdint.h>

////////////////////////////////
// CONSTANTS FOR THE KEYBOARD //
////////////////////////////////

#define HIDD_DEVICE_NAME "ChrisT1 Clavier"
#define TAG "CT1"

////////////////////////////////
// INTERFACES

#define HID_ITF_MOUSEKYB 0
#define HID_ITF_CONSUMER 1
#define HID_ITF_GAMEPAD1 2
#define HID_ITF_GAMEPAD2 3
#define NUMBER_OF_MYKEYS 32

////////////////////////////////
// NON-VOLATILE MEMORY

#define NVS_NAMESPACE "ctrl_cfg"
#define NVS_KEY_GAMEPAD_ITFS "gp_itfs" // gamepads interfaces enable
#define NVS_KEY_GAMEPAD "gp_en"        // gamepads enable
#define NVS_KEY_SOUNDS_LEVEL "sound_lvl" // level of enabled sounds // 0=none, 1=ony usefull, 2=all
#define NVS_KEY_SOUNDS_MUTE "sound_mute" // bypass sounds level to mute

////////////////////////////////
// MATRIX SPECS

#define KB_COLS 8
#define KB_ROWS 17
#define MAX_RAW_KEYS (KB_COLS * KB_ROWS)

#define GPIO_CAPS_LED GPIO_NUM_21

////////////////////////////////
// BUZZER CONFIG

#define BUZZER_GPIO 2
#define BUZZER_CHANNEL LEDC_CHANNEL_0
#define BUZZER_TIMER LEDC_TIMER_0

////////////////////////////////
// KEYBOARD SPECS

#define APP_BUTTON (GPIO_NUM_0) // Use BOOT signal by default
#define NUMBER_OF_SIMULT_KEYS 6

////////////////////////////////
// KEYS

#define M_HID_UNDEF 0x0

// MY KEYS
#define M_HIDMKY_FN_LOCK 0x1
#define M_HIDMK_BACKLIGHT 0x2
#define M_HIDMK_GAMEPADS 0x3

// #define M_HIDMK_SOUNDS_MUTE 0x4
// #define M_HIDMK_SOUNDS_SOME 0x5
// #define M_HIDMK_SOUNDS_ALL 0x6

// LANGUAGES
#define M_HIDMK_MORSE 0x20
#define M_HIDMK_HEXA 0x21
#define M_HIDMK_BIN 0x22

// UC
#define M_HIDUC_SCAN_PREVIOUS 0x40
#define M_HIDUC_PLAY_PAUSE 0x41
#define M_HIDUC_SCAN_NEXT 0x43
#define M_HIDUC_BRIGHTNESS_DECREMENT 0x44
#define M_HIDUC_BRIGHTNESS_INCREMENT 0x45
#define M_HIDUC_AL_CALCULATOR 0x46

// CLASSIC KEYS
#define M_HIDKEY_MUTE 0x60
#define M_HIDKEY_VOLUME_DOWN 0x61
#define M_HIDKEY_VOLUME_UP 0x62
#define M_HIDKEY_FIND 0x63
#define M_HIDKEY_APPLICATION 0x64
#define M_HIDKEY_SCROLLLOCK 0x65
#define M_HIDKEY_ARROW_PAGE_DOWN 0X66
#define M_HIDKEY_ARROW_PAGE_UP 0X67
#define M_HIDKEY_ARROW_BEGIN 0X68
#define M_HIDKEY_ARROW_END 0X69

#define NUMBER_OF_FN_KEYS 128

////////////////////////////////
// GAMEPADS KEYS

// common controls
#define KEY_CONTROLLER_LEFT_STICK_RIGHT 0
#define KEY_CONTROLLER_LEFT_STICK_LEFT 1
#define KEY_CONTROLLER_LEFT_STICK_DOWN 2
#define KEY_CONTROLLER_LEFT_STICK_UP 3

#define KEY_CONTROLLER_RIGHT_STICK_RIGHT 4
#define KEY_CONTROLLER_RIGHT_STICK_LEFT 5
#define KEY_CONTROLLER_RIGHT_STICK_DOWN 6
#define KEY_CONTROLLER_RIGHT_STICK_UP 7

#define KEY_CONTROLLER_DPAD_RIGHT 8
#define KEY_CONTROLLER_DPAD_LEFT 9
#define KEY_CONTROLLER_DPAD_DOWN 10
#define KEY_CONTROLLER_DPAD_UP 11

#define KEY_CONTROLLER_BUTTON_X 12
#define KEY_CONTROLLER_BUTTON_Y 13
#define KEY_CONTROLLER_BUTTON_A 14
#define KEY_CONTROLLER_BUTTON_B 15

#define KEY_CONTROLLER_BUMPER_LEFT 16
#define KEY_CONTROLLER_BUMPER_RIGHT 17

#define KEY_CONTROLLER_BUTTON_VIEW 18
#define KEY_CONTROLLER_BUTTON_HOME 19
#define KEY_CONTROLLER_BUTTON_MENU 20

#define KEY_CONTROLLER_END 21

#define GC_BTN_A (1u << 0)
#define GC_BTN_B (1u << 1)
#define GC_BTN_X (1u << 2)
#define GC_BTN_Y (1u << 3)
#define GC_BTN_LB (1u << 4)
#define GC_BTN_RB (1u << 5)
#define GC_BTN_LT_DIG (1u << 6) /* digital LT press */
#define GC_BTN_RT_DIG (1u << 7) /* digital RT press */
#define GC_BTN_SELECT (1u << 8)
#define GC_BTN_START (1u << 9)
#define GC_BTN_L3 (1u << 10) /* left-stick click  */
#define GC_BTN_R3 (1u << 11) /* right-stick click */
#define GC_BTN_HOME (1u << 12)
#define GC_BTN_SHARE (1u << 13)

const static uint8_t DPADS_DIRECTIONS[3][3] = {
    {GAMEPAD_HAT_UP_LEFT, GAMEPAD_HAT_UP, GAMEPAD_HAT_UP_RIGHT},
    {GAMEPAD_HAT_LEFT, GAMEPAD_HAT_CENTERED, GAMEPAD_HAT_RIGHT},
    {GAMEPAD_HAT_DOWN_LEFT, GAMEPAD_HAT_DOWN, GAMEPAD_HAT_DOWN_RIGHT},
};

// gamepads
#define CONTROLER1_OFFSET 1
#define CONTROLER2_OFFSET (CONTROLER1_OFFSET + KEY_CONTROLLER_END)

#define GC1O(control) ((control) + CONTROLER1_OFFSET)
#define GC2O(control) ((control) + CONTROLER2_OFFSET)

#endif // CONSTANTS_H

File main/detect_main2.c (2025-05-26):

/*
 * SPDX-FileCopyrightText: 2022-2024 Espressif Systems (Shanghai) CO LTD
 *
 * SPDX-License-Identifier: Unlicense OR CC0-1.0
 */

#include <stdlib.h>
#include "esp_log.h"
#include "freertos/FreeRTOS.h"
#include "freertos/task.h"
#include "tinyusb.h"
#include "class/hid/hid_device.h"
#include "driver/gpio.h"
#include <vector>
#include <string>

#define APP_BUTTON (GPIO_NUM_0) // Use BOOT signal by default
static const char *TAG = "example";

/************* TinyUSB descriptors ****************/

#define TUSB_DESC_TOTAL_LEN (TUD_CONFIG_DESC_LEN + CFG_TUD_HID * TUD_HID_DESC_LEN)

/**
 * @brief HID report descriptor
 *
 * In this example we implement Keyboard + Mouse HID device,
 * so we must define both report descriptors
 */
const uint8_t hid_report_descriptor[] = {
    TUD_HID_REPORT_DESC_KEYBOARD(HID_REPORT_ID(HID_ITF_PROTOCOL_KEYBOARD)),
    TUD_HID_REPORT_DESC_MOUSE(HID_REPORT_ID(HID_ITF_PROTOCOL_MOUSE))};

/**
 * @brief String descriptor
 */
const char *hid_string_descriptor[5] = {
    // array of pointer to string descriptors
    (char[]){0x0c, 0x04},    // 0: is supported language is French, for English (0x0409)
    "MagicTINTIN",           // 1: Manufacturer
    "ChrisT1 Clavier",       // 2: Product
    "123456",                // 3: Serials, should use chip ID
    "Example HID interface", // 4: HID
};

/**
 * @brief Configuration descriptor
 *
 * This is a simple configuration descriptor that defines 1 configuration and 1 HID interface
 */
static const uint8_t hid_configuration_descriptor[] = {
    // Configuration number, interface count, string index, total length, attribute, power in mA
    TUD_CONFIG_DESCRIPTOR(1, 1, 0, TUSB_DESC_TOTAL_LEN, TUSB_DESC_CONFIG_ATT_REMOTE_WAKEUP, 100),

    // Interface number, string index, boot protocol, report descriptor len, EP In address, size & polling interval
    TUD_HID_DESCRIPTOR(0, 4, false, sizeof(hid_report_descriptor), 0x81, 16, 10),
};

/********* TinyUSB HID callbacks ***************/

// Invoked when received GET HID REPORT DESCRIPTOR request
// Application return pointer to descriptor, whose contents must exist long enough for transfer to complete
uint8_t const *tud_hid_descriptor_report_cb(uint8_t instance)
{
    // We use only one interface and one HID report descriptor, so we can ignore parameter 'instance'
    return hid_report_descriptor;
}

// Invoked when received GET_REPORT control request
// Application must fill buffer report's content and return its length.
// Return zero will cause the stack to STALL request
uint16_t tud_hid_get_report_cb(uint8_t instance, uint8_t report_id, hid_report_type_t report_type, uint8_t *buffer, uint16_t reqlen)
{
    (void)instance;
    (void)report_id;
    (void)report_type;
    (void)buffer;
    (void)reqlen;

    return 0;
}

// Invoked when received SET_REPORT control request or
// received data on OUT endpoint ( Report ID = 0, Type = 0 )
void tud_hid_set_report_cb(uint8_t instance, uint8_t report_id, hid_report_type_t report_type, uint8_t const *buffer, uint16_t bufsize)
{
}

/********* Application ***************/

typedef enum
{
    MOUSE_DIR_RIGHT,
    MOUSE_DIR_DOWN,
    MOUSE_DIR_LEFT,
    MOUSE_DIR_UP,
    MOUSE_DIR_MAX,
} mouse_dir_t;

#define DISTANCE_MAX 125
#define DELTA_SCALAR 5

// static void mouse_draw_square_next_delta(int8_t *delta_x_ret, int8_t *delta_y_ret)
// {
//     static mouse_dir_t cur_dir = MOUSE_DIR_RIGHT;
//     static uint32_t distance = 0;

//     // Calculate next delta
//     if (cur_dir == MOUSE_DIR_RIGHT)
//     {
//         *delta_x_ret = DELTA_SCALAR;
//         *delta_y_ret = 0;
//     }
//     else if (cur_dir == MOUSE_DIR_DOWN)
//     {
//         *delta_x_ret = 0;
//         *delta_y_ret = DELTA_SCALAR;
//     }
//     else if (cur_dir == MOUSE_DIR_LEFT)
//     {
//         *delta_x_ret = -DELTA_SCALAR;
//         *delta_y_ret = 0;
//     }
//     else if (cur_dir == MOUSE_DIR_UP)
//     {
//         *delta_x_ret = 0;
//         *delta_y_ret = -DELTA_SCALAR;
//     }

//     // Update cumulative distance for current direction
//     distance += DELTA_SCALAR;
//     // Check if we need to change direction
//     if (distance >= DISTANCE_MAX)
//     {
//         distance = 0;
//         cur_dir++;
//         if (cur_dir == MOUSE_DIR_MAX)
//         {
//             cur_dir = 0;
//         }
//     }
// }
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

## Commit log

2025-04-14 fix: uploading stage
2025-04-15 doc: wiring pin/gpio
2025-04-16 fix: rx tx wires conflict
2025-04-16 feat: back/skip buttons
2025-04-17 feat: sending keys (apparently not the right ones)
    en plus il écrit tout seul commme un con visiblement, c'est super
2025-04-17 fix: gpios were also used by usb... + debug stuff
    [main.cc]
2025-04-17 fix: sending modifiers as keys
    [main.cc]
2025-04-20 bug: makes grub crash :/
    RAAAAAAAAAAAAAAAAAAAAAAAAAAAAAA
    [main.cc]
2025-04-20 fix: keyboard working in grub again
    [main.cc]
2025-04-20 chore: setup pour que ça marche
2025-04-21 chore: c'est juste de la grande merde
2025-04-21 feat: trou du cul bien sûr il faut changer la conf !
2025-04-22 feat: adding 3d model directory
    [v0.blend]
2025-04-23 chore: trying to use plane
    [v0.blend]
2025-04-23 feat: bevel key params
    [v0.blend]
2025-04-23 feat: split on spaces
    [v0.blend]
2025-04-23 feat: key arrays
    [v0.blend]
2025-04-23 doc: measuring keys
    [v0.blend]
2025-04-23 doc: adding better reference (800mm focal) and measures
    [v0.blend]
2025-04-23 doc: adding all keyboard (except num pad) measurements
    [v0.blend]
2025-04-23 doc: all keys are measured + "Over" 3d model
    [v0.blend]
2025-05-01 fix: </> keys not working (EU 2)
    Fixes #3
    [main.cc]
2025-05-03 fix: not registering first already pressed key
    [main.cc]
2025-05-26 feat: adding base kicad pcb ( + esp lib)
    [mainPCB.kicad_pcb, mainPCB.kicad_sch]
2025-05-26 wip pccb
    [mainPCB.kicad_pcb, mainPCB.kicad_sch]
2025-05-26 ignoring kicad backups in repo
2025-05-29 chore: partial fix with a blocking algorithm #5 (remember previous keys)
    [main.cc]
2025-05-30 chore: improvement (less ghosts, but still some at press) #5
    do not watch for the whole rectangle but just for one of the 4 triangles of each rectangle
    ←↑↓ do not produces 0 now, but ←↑→↓ still produces a 1
    zed still produces a s sometimes at press
2025-05-30 doc: how to prevent ghost keys on diodeless (#5)
2025-05-30 wip: filtered raw buffer (#5) no visible improvement
2025-05-30 fix: reusing open drain in/out in each scan
    Fixes #5
    Closes #6
    [main.cc]
2025-06-08 feat: adding 40pin connector
2025-06-08 feat: 30pins connector
2025-06-08 oskur, cette personne fait sûrement n'imp mais ne s'en aperçois même pas (découvrez son histoire)
    [mainPCB.kicad_pcb, mainPCB.kicad_sch]
2025-06-08 doc: esp32 doc
2025-06-08 feat: caps lock LED yay
2025-06-08 pcb: hmmm yes that's better with labels
    [mainPCB.kicad_sch]
2025-06-15 doc: adding resistor information
2025-06-15 wip: starting pcb wiring
    [mainPCB.kicad_pcb, mainPCB.kicad_sch]
2025-06-15 wip: starting no crossing cable
    [mainPCB.kicad_pcb, mainPCB.kicad_sch]
2025-06-22 feat: bicolor over 3d model version
    [v0.2.blend, v0.2.stl, v0.2c.stl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]
2025-06-22 feat: spliting model for 3D printing
    [split1c.stl, split1m.stl]
2025-06-24 feat: bluetooth device
2025-06-24 fix: only disable key to ble only if necessary
    [main.cc]
2025-08-03 chore: switching to C (as it is C)
2026-02-22 chore: adding backlight connectors
    [mainPCB.kicad_pcb, mainPCB.kicad_sch]
2026-02-28 feat: adding NPN for caps led
    [mainPCB.kicad_pcb, mainPCB.kicad_sch]
2026-03-01 chore: more cables
    [mainPCB.kicad_pcb, mainPCB.kicad_sch]
2026-05-01 fix: consumer empty buffer for key release
    Closes #11
    [main.c]
2026-05-03 feat: storing configuration in nvs
    [configuration.h]
2026-05-03 feat: indicating gamepad conf at startup using task on caps lock led
2026-05-05 feat: interface settings != enabled gamepad
    Closes #16
    No more reboot/cycling over configurations needed
    [configuration.h]
2026-05-06 fix: 2nd dpad never sending data
    [main.c]
2026-05-06 feat: binding all other gamepad keys
    [constants.h, main.c]
2026-05-17 feat: control the keyboard's sound
    Closes #14
    [configuration.h]
